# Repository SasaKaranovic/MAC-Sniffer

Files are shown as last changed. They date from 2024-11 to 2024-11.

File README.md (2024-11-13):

# MAC Sniffer

## What is this project about?

MAC Sniffer (http://www.youtube.com/watch?v=tu_N1xqSLxA "MAC Sniffer")

In the above video you will learn what is a MAC Sniffer, why I built it and how you can build your own.

If you are looking for a TL;DR version: It is a simple stand-alone tool used to read network equipment MAC address and display it on screen as text and a QR code. And it can also work with devices that don't even have an OS installed.

If you find this video/project useful, I would really love to hear from you.
<br/><br/>

## Can I buy one?

No. But you can easily build your own. :)
<br/><br/>

## Can I build my own?

Yes! It is super simple and uses only off-the-shelf parts.

You will need

- [Wiznet W5500-EVB-Pico](https://docs.wiznet.io/Product/iEthernet/W5500/w5500-evb-pico) development board
- 1.69" 240x280 ST7789V2 Display Module ([Seeed Studio](https://www.seeedstudio.com/1-69inch-240-280-Resolution-IPS-LCD-Display-Module-p-5755.html),  [Waveshare](https://www.waveshare.com/1.69inch-lcd-module.htm))
<br/><br/>

### 1. Prepare the development board (Install Circuit Python)

1. Place the development board into bootloader mode (hold `BOOTSEL` button and then connect USB cable.
2. Pico2040 will report as a new USB drive
3. Copy `adafruit-circuitpython-wiznet_w5500_evb_pico-en_US-9.1.4.uf2` file from the firmware folder to the Pico2040
4. The board will reload and new `CIRCUITPY` drive will appear

### 2. Setup Python code

1. Copy all files from `pico_content` folder to root of your `CIRCUITPY` drive
2. Power cycle the board

### 3. Wire the display

Follow the below table to connect your display to the Pico2040

| Display | Pico2040 |
| --- | --- |
| VCC | 3V3 |
| GND | GND |
| DIN | GP19 |
| CLK | GP18 |
| CS | GP22 |
| DC | GP26 |
| RST | GP27 |
| BL | GP28 |

<br><br>

## Useful links

Blog page: https://sasakaranovic.com/projects/mac-sniffer/

YouTube video: http://www.youtube.com/watch?v=tu_N1xqSLxA

<br/><br/>

#### Sasa Karanovic

<a href="https://sasakaranovic.com/" target="_blank" title="Sasa Karanovic Home Page"> Home Page</a> &nbsp;&middot;&nbsp;
<a href="https://youtube.com/c/sasakaranovic" target="_blank" title="Sasa Karanovic on YouTube"> YouTube</a> &nbsp;&middot;&nbsp;
<a href="https://github.com/sasakaranovic" target="_blank" title="Sasa Karanovic on GitHub"> GitHub</a> &nbsp;&middot;&nbsp;
<a href="https://twitter.com/_sasakaranovic_" target="_blank" title="Sasa Karanovic on Twitter"> Twitter</a> &nbsp;&middot;&nbsp;
<a href="https://instagram.com/_sasakaranovic_" target="_blank" title="Sasa Karanovic on Instagram"> Instagram</a> &nbsp;&middot;&nbsp;
<a href="https://github.com/sponsors/SasaKaranovic" target="_blank" title="Sponsor on GitHub"> Sponsor on GitHub</a>

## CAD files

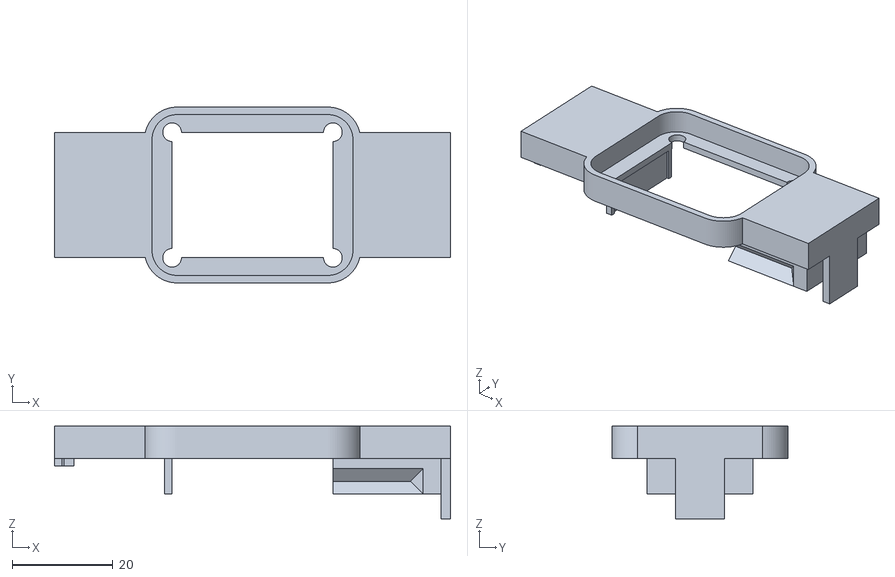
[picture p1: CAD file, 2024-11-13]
enclosure/Top-Display.stl
78.8 x 35.0 x 18.5

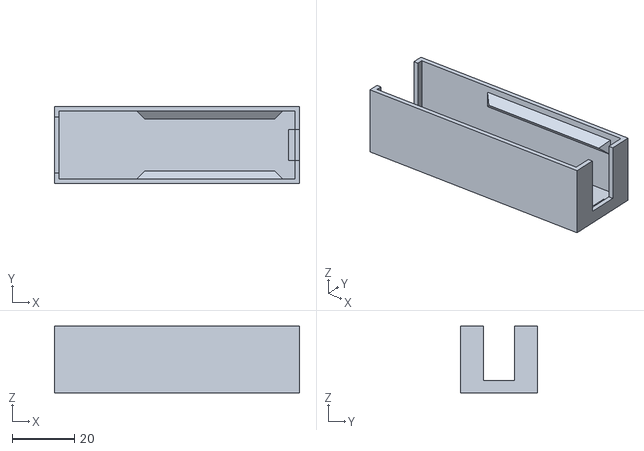
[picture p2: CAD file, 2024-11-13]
enclosure/Bottom.stl
78.8 x 24.8 x 21.5

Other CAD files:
enclosure/MacSniffer_Case.f3d

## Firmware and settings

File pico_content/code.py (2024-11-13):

import board
from skdisplay import SKDisplay
from sketh import SKEthernet

print("------")
print("MAC Sniffer v0.1")
print("https://github.com/SasaKaranovic/MAC-Sniffer")
print("------")

# Setup SPI bus
spi_bus = board.SPI()

display = SKDisplay(spi_bus)
display.clear()
display.show_text(37, 120, "Setting up...", scale=1)
display.backlight(True)
eth = SKEthernet(spi_bus)

state = 0

while True:
    eth_state = eth.tick()
    
    if eth_state != state:
        if eth_state == -1:
            display.clear()
            display.show_text(37, 120, "Waiting for eth...", scale=1)

        elif eth_state == 0:
            if state != 1:
                display.clear()
                display.show_text(37, 120, "Listening...")

        elif eth_state == 1:
            if state != 1:
                mac = eth.get_last_mac()
                display.clear()
                display.show_qr_and_text(mac)
       
        state = eth_state

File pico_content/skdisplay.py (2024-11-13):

import time
import board
import digitalio
import terminalio
import displayio
import adafruit_miniqr
from fourwire import FourWire
from adafruit_display_text import label
from adafruit_st7789 import ST7789

class SKDisplay:
    def __init__(self, spi):
        self.display_width = 280
        self.display_height = 240
        self.display_rotation = 90
        
        # Setup backlight
        self.pin_bl = digitalio.DigitalInOut(board.GP28)
        self.pin_bl.direction = digitalio.Direction.OUTPUT
        self.pin_bl.value = False
        
        displayio.release_displays()

        self.spi = spi
        tft_cs = board.GP22
        tft_dc = board.GP26
        tft_reset = board.GP27
        
        self.display_bus = FourWire(self.spi, command=tft_dc, chip_select=tft_cs, reset=tft_reset)
        self.display = ST7789(self.display_bus, width=self.display_width, height=self.display_height, rowstart=20, rotation=90)
        
        # Display resources
        self.splash = displayio.Group()
        self.display.root_group = self.splash

    def clear(self, color=0x000000):
        try:
            for i in range(0, 10):
                self.splash.pop(i)
        except:
            pass
        color_bitmap = displayio.Bitmap(self.display_width, self.display_height, 1)
        color_palette = displayio.Palette(1)
        color_palette[0] = color

        bg_sprite = displayio.TileGrid(color_bitmap, pixel_shader=color_palette, x=0, y=0)
        self.splash.append(bg_sprite)
    
    def show_text(self, x, y, text, scale=2, color=0xFFFF00):
        # Draw a label
        text_group = displayio.Group(scale=2, x=x, y=y)
        text_area = label.Label(terminalio.FONT, text=text, color=color)
        text_group.append(text_area)  # Subgroup for text scaling
        self.splash.append(text_group)
    
    def backlight(self, enable):
        self.pin_bl.value = enable

    def test(self):
        # Make the display context
        splash = displayio.Group()
        self.display.root_group = splash
        color_bitmap = displayio.Bitmap(self.display_width, 240, 1)
        color_palette = displayio.Palette(1)
        color_palette[0] = 0x00FF00  # Bright Green

        bg_sprite = displayio.TileGrid(color_bitmap, pixel_shader=color_palette, x=0, y=0)
        splash.append(bg_sprite)

        # Draw a smaller inner rectangle
        inner_bitmap = displayio.Bitmap(240, 200, 1)
        inner_palette = displayio.Palette(1)
        inner_palette[0] = 0xAA0088  # Purple
        inner_sprite = displayio.TileGrid(inner_bitmap, pixel_shader=inner_palette, x=20, y=20)
        splash.append(inner_sprite)

        # Draw a label
        text_group = displayio.Group(scale=2, x=37, y=120)
        text = "f4:12:fa:27:6c:60"
        text_area = label.Label(terminalio.FONT, text=text, color=0xFFFF00)
        text_group.append(text_area)  # Subgroup for text scaling
        splash.append(text_group)

    def show_qr_and_text(self, data):
        # generate the 1-pixel-per-bit bitmap
        qr_bitmap = self.qr_to_bitmap(data)
        # We'll draw with a classic black/white palette
        palette = displayio.Palette(2)
        palette[0] = 0xFFFFFF
        palette[1] = 0x000000

        # scale = 3
        scale = min(
            self.display.width // qr_bitmap.width, (self.display.height - 50) // qr_bitmap.height
        )

        # QR at the bottom
        pos_x = int(((self.display.width / scale) - qr_bitmap.width) / 2)
        pos_y = int(((self.display.height / scale) - qr_bitmap.height))
        qr_img = displayio.TileGrid(qr_bitmap, pixel_shader=palette, x=pos_x, y=pos_y)

        qr_group = displayio.Group(scale=scale)
        qr_group.append(qr_img)
        self.splash.append(qr_group)

        # Add text
        # Draw a label
        text_area = label.Label(terminalio.FONT, text=data, color=0xFFFF00)
        text_scale = 2
        text_width = text_area.width * text_scale
        text_height = text_area.height * text_scale
        pos_x = int((self.display.width - text_width) /2 )
        pos_y = 20
        text_group = displayio.Group(scale=text_scale, x=pos_x, y=pos_y)
        text_group.append(text_area)  # Subgroup for text scaling
        self.splash.append(text_group)


    def show_qr(self, data):
        # generate the 1-pixel-per-bit bitmap
        qr_bitmap = self.qr_to_bitmap(data)
        # We'll draw with a classic black/white palette
        palette = displayio.Palette(2)
        palette[0] = 0xFFFFFF
        palette[1] = 0x000000

        # scale = 3
        scale = min(
            self.display.width // qr_bitmap.width, self.display.height // qr_bitmap.height
        )

        # then center it!
        pos_x = int(((self.display.width / scale) - qr_bitmap.width) / 2)
        pos_y = int(((self.display.height / scale) - qr_bitmap.height) / 2)
        qr_img = displayio.TileGrid(qr_bitmap, pixel_shader=palette, x=pos_x, y=pos_y)

        qr_group = displayio.Group(scale=scale)
        qr_group.append(qr_img)
        self.splash.append(qr_group)



    def qr_to_bitmap(self, data):
        qr = adafruit_miniqr.QRCode()
        qr.add_data(data)
        qr.make()

        # monochome (2 color) palette
        BORDER_PIXELS = 2

        # bitmap the size of the screen, monochrome (2 colors)
        bitmap = displayio.Bitmap(
            qr.matrix.width + 2 * BORDER_PIXELS, qr.matrix.height + 2 * BORDER_PIXELS, 2
        )
        # raster the QR code
        for y in range(qr.matrix.height):  # each scanline in the height
            for x in range(qr.matrix.width):
                if qr.matrix[x, y]:
                    bitmap[x + BORDER_PIXELS, y + BORDER_PIXELS] = 1
                else:
                    bitmap[x + BORDER_PIXELS, y + BORDER_PIXELS] = 0
        return bitmap
